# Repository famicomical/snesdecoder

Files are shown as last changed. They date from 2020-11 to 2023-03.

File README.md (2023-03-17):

# SNES Controller Decoder #
It's a receiver for Super Nintendo Controllers.

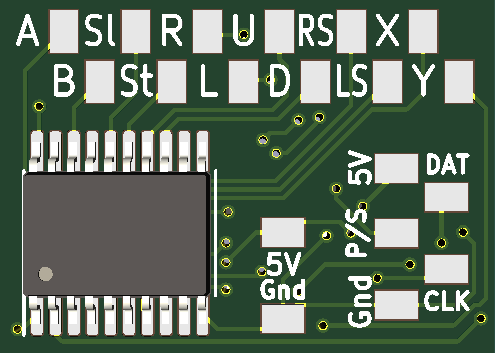
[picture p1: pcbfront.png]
front


I use it to drive the button inputs on the IS-NITRO CAPTURE dev console.
With some soldering skills, one could adapt it for any application where up
to twelve switches need to be controlled from a distance. For example, you can use the snesdecoder 
to play your Neo Geo console or JAMMA arcade game with your SNES controller.

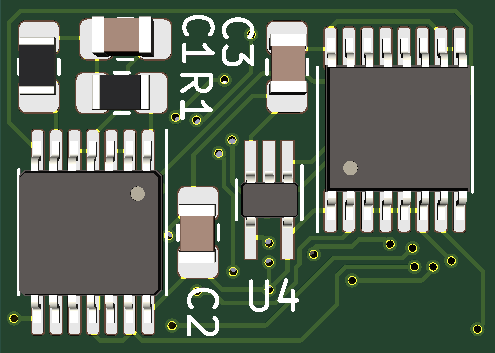
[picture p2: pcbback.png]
back


## Design Sketch ##
The SNES controller takes 4 inputs (GND, 5V, CLK, and LATCH) and sends one serial output for button press data.
This board routes power to the controller and provides the clock & latch signals to drive it.
The button data from the controller is sent back to the decoder pcb, which outputs the buttons in parallel.

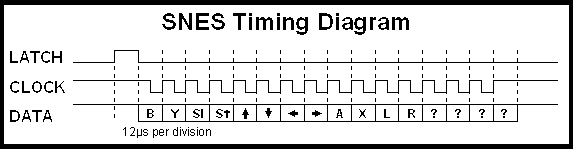
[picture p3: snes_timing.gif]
SNES Timing Diagram


The clock is generated using a ring oscillator whose period is set by an external RC time constant. See [Fairchild AN-118](https://www.onsemi.com/pub/Collateral/AN-118.pdf.pdf). 
The ripple carry output of a 4-bit counter supplies the latch signal. This way, the SNES controller is polled every 16 clock cycles, which is enough time to transmit a full data packet. The counter also drives the register clock on the shift register(s), thereby updating the open drain outputs to reflect the button data of the preceding packet until the next packet is received.

To produce a working board, some quirks were taken into account:

The SNES button data is logic high when a button is NOT pressed, so the data stream needs to be inverted before going to the shift register(s) for canonical switch behavior, i.e. not pressed -> open circuit. Also, the latch and clock outputs going to the controller need dedicated buffers, otherwise the interference between the wires in the controller cable feeds back to the decoder board, causing malfunctions. Lastly, the clock signal being fed to the shift register(s) should be inverted so the button states are sampled from the data stream roughly at the midpoint of each button's time-bin.

Detailed info about the SNES contoller can be found on [GameSX](https://gamesx.com/controldata/snesdat.htm)

## Motivation ##
This project was inspired by an [old forum post](https://nfggames.com/forum2/index.php?msg=26296) on NFGgames.

I wanted to use my SNES controller on other consoles, but I felt a universal computer would be 
overkill for accomplishing that. All of the existing solutions that I'm aware of use a computer or custom logic. 
With discrete components that don't require programming, this design is trasparent about what it does, and is
reminiscent of the simpler times when transistors were more expensive and packaging less so by comparison :P

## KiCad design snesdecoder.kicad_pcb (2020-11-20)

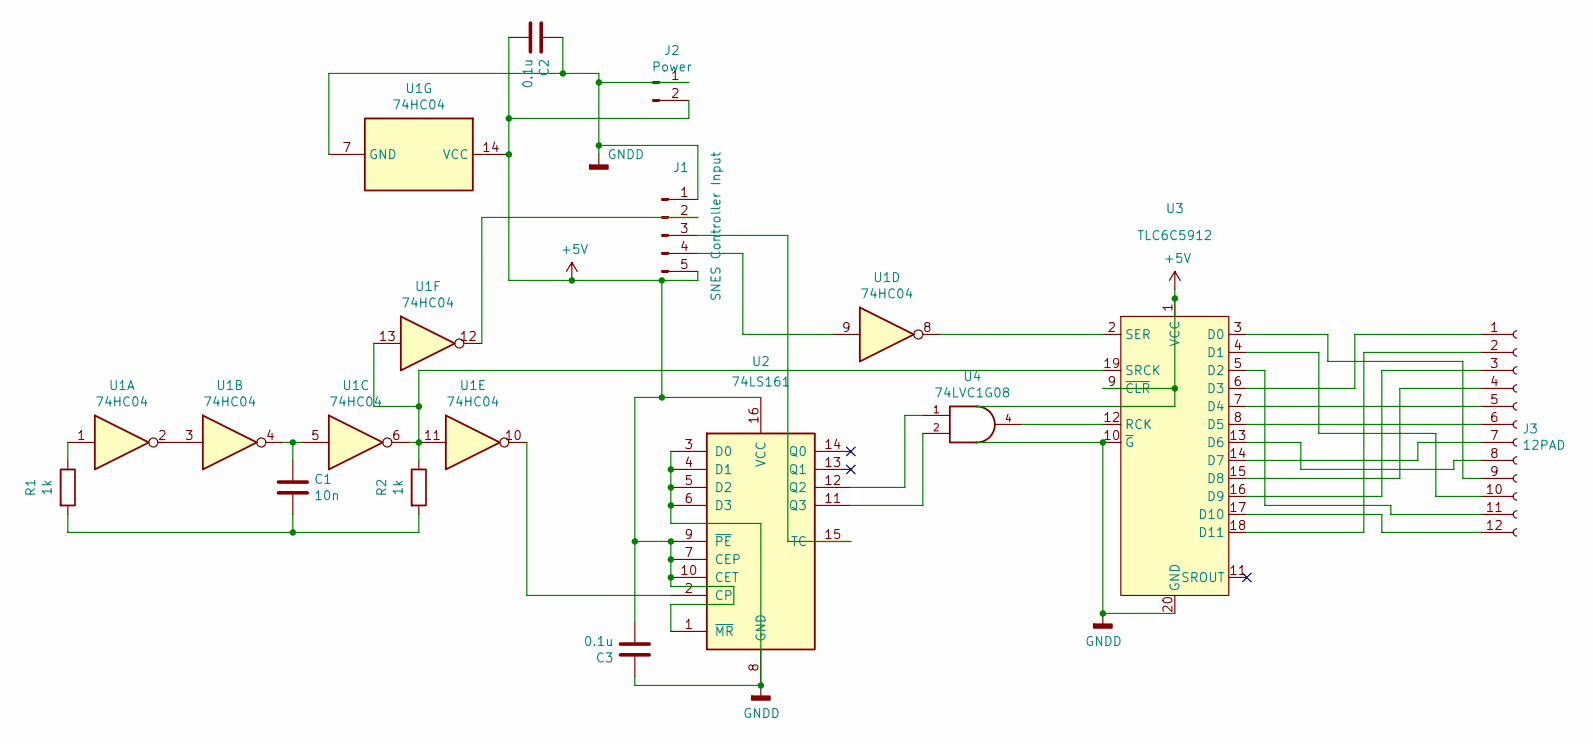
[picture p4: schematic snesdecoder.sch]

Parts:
C1: 10n; C_0805_2012Metric_Pad1.15x1.40mm_HandSolder
C2, C3: 0.1u; C_0805_2012Metric_Pad1.15x1.40mm_HandSolder
J1: SNES Controller Input; Connector_Wire_5PAD
J2: Power; 2PAD_Pwrr
J3: 12PAD
R1, R2: 1k; R_0805_2012Metric_Pad1.15x1.40mm_HandSolder
U1: 74HC04; SOIC-14_3.9x8.7mm_P1.27mm
U2: 74LS161; SOIC-16_3.9x9.9mm_P1.27mm
U3: TLC6C5912; SOIC-20W_7.5x12.8mm_P1.27mm
U4: 74LVC1G08; SOT-353_SC-70-5_Handsoldering

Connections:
+5V: C2.2, C3.2, J1.5, J2.2, U1.14 (VCC), U2.1 (~MR), U2.7 (CEP), U2.9 (~PE), U2.10 (CET), U2.16 (VCC), U3.1 (VCC), U3.9 (~CLR), U4.5 (VCC)
GND: C2.1, C3.1, J1.1, J2.1, U1.7 (GND), U2.3 (D0), U2.4 (D1), U2.5 (D2), U2.6 (D3), U2.8 (GND), U3.10 (~G), U3.20 (GND), U4.3 (GND)
unnamed: C1.1, U1.4, U1.5
unnamed: C1.2, R1.2, R2.2
unnamed: J1.2, U1.12
unnamed: J1.3, U2.15 (TC)
unnamed: J1.4, U1.9
unnamed: J3.1, U3.6 (D3)
unnamed: J3.2, U3.18 (D11)
unnamed: J3.3, U3.16 (D9)
unnamed: J3.4, U3.15 (D8)
unnamed: J3.5, U3.7 (D4)
unnamed: J3.6, U3.8 (D5)
unnamed: J3.7, U3.14 (D7)
unnamed: J3.8, U3.13 (D6)
unnamed: J3.9, U3.3 (D0)
unnamed: J3.10, U3.4 (D1)
unnamed: J3.11, U3.5 (D2)
unnamed: J3.12, U3.17 (D10)
unnamed: R1.1, U1.1
unnamed: R2.1, U1.6, U1.11, U1.13, U3.19 (SRCK)
unnamed: U1.2, U1.3
unnamed: U1.8, U3.2 (SER)
unnamed: U1.10, U2.2 (CP)
unnamed: U2.11 (Q3), U4.2
unnamed: U2.12 (Q2), U4.1
unnamed: U3.12 (RCK), U4.4

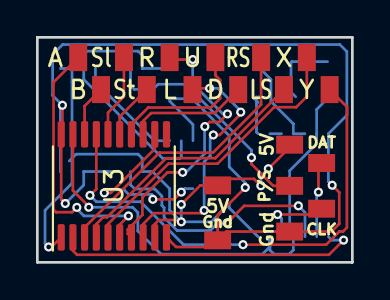
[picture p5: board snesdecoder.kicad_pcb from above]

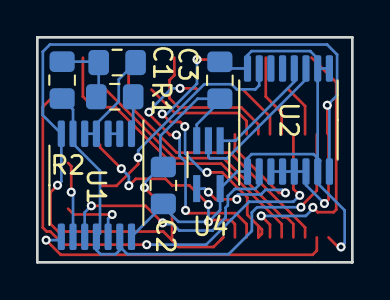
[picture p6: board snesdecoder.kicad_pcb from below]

Board: 2 copper layers, 17.5 x 12.5 mm, 12 parts (8 on the bottom side), 27 nets.

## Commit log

2020-11-09 Initial commit: Snes Decoder V1 ready
    [snesdecoder-B_Cu.gbl, snesdecoder-B_Mask.gbs, snesdecoder-B_SilkS.gbo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]
2020-11-09 updated gerbers
    [snesdecoder-B_Cu.gbl, snesdecoder-B_Mask.gbs, snesdecoder-B_SilkS.gbo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]
2020-11-09 update gerbers
    [snesdecoder-B_Cu.gbl, snesdecoder-B_Mask.gbs, snesdecoder-B_SilkS.gbo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]
2020-11-15 update to V2: change schema, pcb layout, datasheets
    [snesdecoder.dsn, snesdecoder.kicad_pcb, snesdecoder.sch]
2020-11-15 gerbers to v2
    [snesdecoder-B_Cu.gbl, snesdecoder-B_Mask.gbs, snesdecoder-B_SilkS.gbo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]
2020-11-20 snesdecoder compact release
    [snesdecoder-B_Cu.gbl, snesdecoder-B_Mask.gbs, snesdecoder-B_SilkS.gbo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]
2020-11-20 fix sch
    [snesdecoder.sch]
